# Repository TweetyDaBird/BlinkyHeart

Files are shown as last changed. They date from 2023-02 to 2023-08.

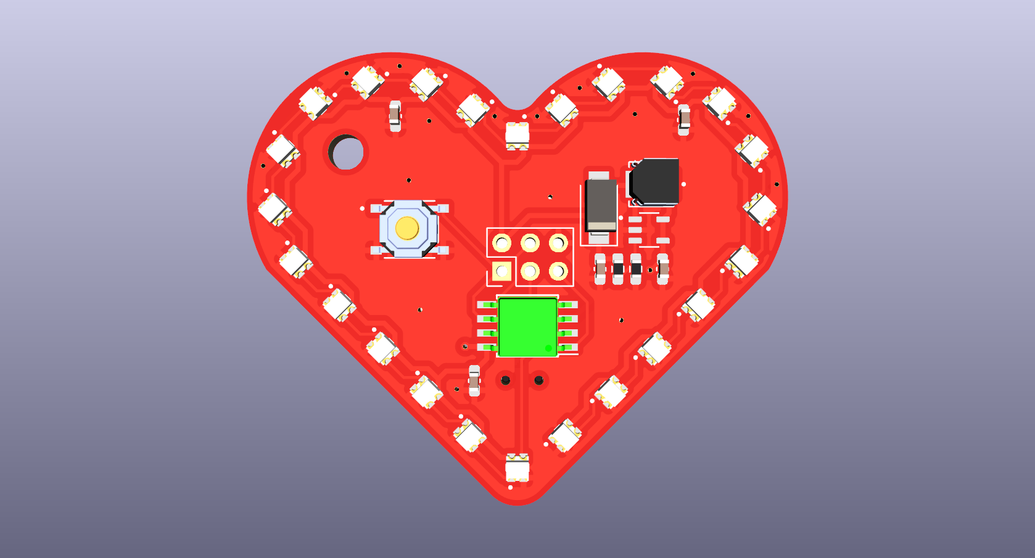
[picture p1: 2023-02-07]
BlinkyHeart/BlinkyHeart.png

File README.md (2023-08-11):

# BlinkyRGB
Blinky RGB Keychains in various shapes and sizes.

Uses an Microchip ATTINY85 MCU, and is powered by a CR2032 coin cell.

BlinkyHeart
BlinkyHeart_back
BlinkyStar
BlinkySmiley

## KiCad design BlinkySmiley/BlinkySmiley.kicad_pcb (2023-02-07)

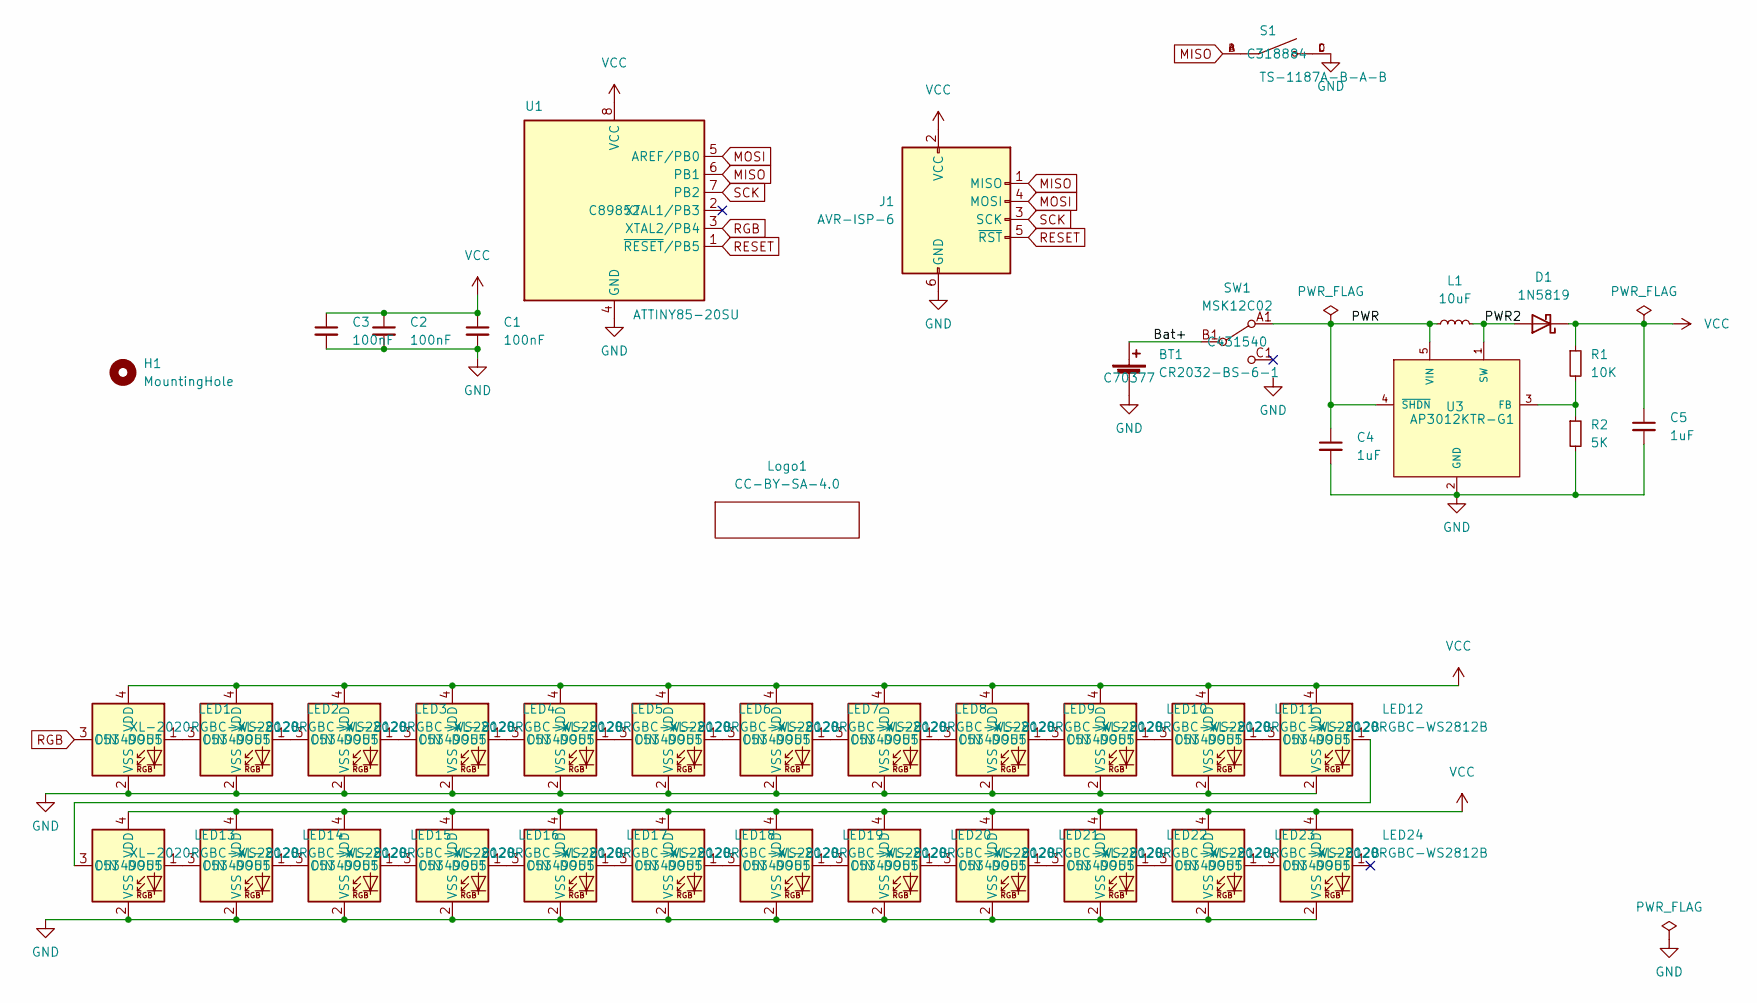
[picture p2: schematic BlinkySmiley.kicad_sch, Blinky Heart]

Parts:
BT1: CR2032-BS-6-1; BAT_CR2032-BS-6-1; LCSC C70377
C1, C2, C3: 100nF; C_0603_1608Metric_Pad1.08x0.95mm_HandSolder; LCSC C14663
C4, C5: 1uF; C_0603_1608Metric_Pad1.08x0.95mm_HandSolder; LCSC C15849
D1: 1N5819; D_SMA; LCSC C437199
H1: MountingHole; MountingHole_3.2mm_M3
J1: AVR-ISP-6; PinHeader_2x03_P2.54mm_Vertical
L1: 10uF; IND_FDSD0420-H-100M=P3; LCSC C1329533
LED1, LED2, LED3, LED4, LED5, LED6, LED7, LED8, LED9, LED10, LED11, LED12, LED13, LED14, LED15, LED16, LED17, LED18, LED19, LED20, LED21, LED22, LED23, LED24: XL-2020RGBC-WS2812B; LED_WS2812-2020; LCSC C5349955
Logo1: CC-BY-SA-4.0; CC_BY_SA_40
R1: 10K; R_0603_1608Metric_Pad0.98x0.95mm_HandSolder; LCSC C3017715
R2: 5K; R_0603_1608Metric_Pad0.98x0.95mm_HandSolder; LCSC C2828621
S1: TS-1187A-B-A-B; SW_TS-1187A-B-A-B; PARTREV A0; LCSC C318884
SW1: MSK12C02; LCSC C431540
U1: ATTINY85-20SU; SOIC-8W_5.3x5.3mm_P1.27mm; LCSC C89852
U3: AP3012KTR-G1; SOT95P280X145-5N; PARTREV 1.6; LCSC C102618

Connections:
/Bat+: BT1.1 (+), SW1.B1 (COM)
/PWR: C4.1, L1.1, SW1.A1 (A), U3.4 (~SHDN), U3.5 (VIN)
/PWR2: D1.2 (A), L1.2, U3.1 (SW)
GND: BT1.2 (-), C1.2, C2.2, C3.2, C4.2, C5.2, J1.6 (GND), LED1.2 (VSS), LED2.2 (VSS), LED3.2 (VSS), LED4.2 (VSS), LED5.2 (VSS), LED6.2 (VSS), LED7.2 (VSS), LED8.2 (VSS), LED9.2 (VSS), LED10.2 (VSS), LED11.2 (VSS), LED12.2 (VSS), LED13.2 (VSS), LED14.2 (VSS), LED15.2 (VSS), LED16.2 (VSS), LED17.2 (VSS), LED18.2 (VSS), LED19.2 (VSS), LED20.2 (VSS), LED21.2 (VSS), LED22.2 (VSS), LED23.2 (VSS), LED24.2 (VSS), R2.2, S1.C, S1.D, SW1.MP (GND), U1.4 (GND), U3.2 (GND)
MISO: J1.1 (MISO), S1.A, S1.B, U1.6 (PB1)
MOSI: J1.4 (MOSI), U1.5 (AREF/PB0)
unnamed: LED1.1 (DOUT), LED2.3 (DIN)
unnamed: LED2.1 (DOUT), LED3.3 (DIN)
unnamed: LED3.1 (DOUT), LED4.3 (DIN)
unnamed: LED4.1 (DOUT), LED5.3 (DIN)
unnamed: LED5.1 (DOUT), LED6.3 (DIN)
unnamed: LED6.1 (DOUT), LED7.3 (DIN)
unnamed: LED7.1 (DOUT), LED8.3 (DIN)
unnamed: LED8.1 (DOUT), LED9.3 (DIN)
unnamed: LED10.1 (DOUT), LED11.3 (DIN)
unnamed: LED9.1 (DOUT), LED10.3 (DIN)
unnamed: LED11.1 (DOUT), LED12.3 (DIN)
unnamed: LED12.1 (DOUT), LED13.3 (DIN)
unnamed: LED13.1 (DOUT), LED14.3 (DIN)
unnamed: LED14.1 (DOUT), LED15.3 (DIN)
unnamed: LED15.1 (DOUT), LED16.3 (DIN)
unnamed: LED16.1 (DOUT), LED17.3 (DIN)
unnamed: LED17.1 (DOUT), LED18.3 (DIN)
unnamed: LED18.1 (DOUT), LED19.3 (DIN)
unnamed: LED19.1 (DOUT), LED20.3 (DIN)
unnamed: LED20.1 (DOUT), LED21.3 (DIN)
unnamed: LED21.1 (DOUT), LED22.3 (DIN)
unnamed: LED22.1 (DOUT), LED23.3 (DIN)
unnamed: LED23.1 (DOUT), LED24.3 (DIN)
unnamed: R1.2, R2.1, U3.3 (FB)
RESET: J1.5 (~RST), U1.1 (~RESET/PB5)
RGB: LED1.3 (DIN), U1.3 (XTAL2/PB4)
SCK: J1.3 (SCK), U1.7 (PB2)
VCC: C1.1, C2.1, C3.1, C5.1, D1.1 (K), J1.2 (VCC), LED1.4 (VDD), LED2.4 (VDD), LED3.4 (VDD), LED4.4 (VDD), LED5.4 (VDD), LED6.4 (VDD), LED7.4 (VDD), LED8.4 (VDD), LED9.4 (VDD), LED10.4 (VDD), LED11.4 (VDD), LED12.4 (VDD), LED13.4 (VDD), LED14.4 (VDD), LED15.4 (VDD), LED16.4 (VDD), LED17.4 (VDD), LED18.4 (VDD), LED19.4 (VDD), LED20.4 (VDD), LED21.4 (VDD), LED22.4 (VDD), LED23.4 (VDD), LED24.4 (VDD), R1.1, U1.8 (VCC)

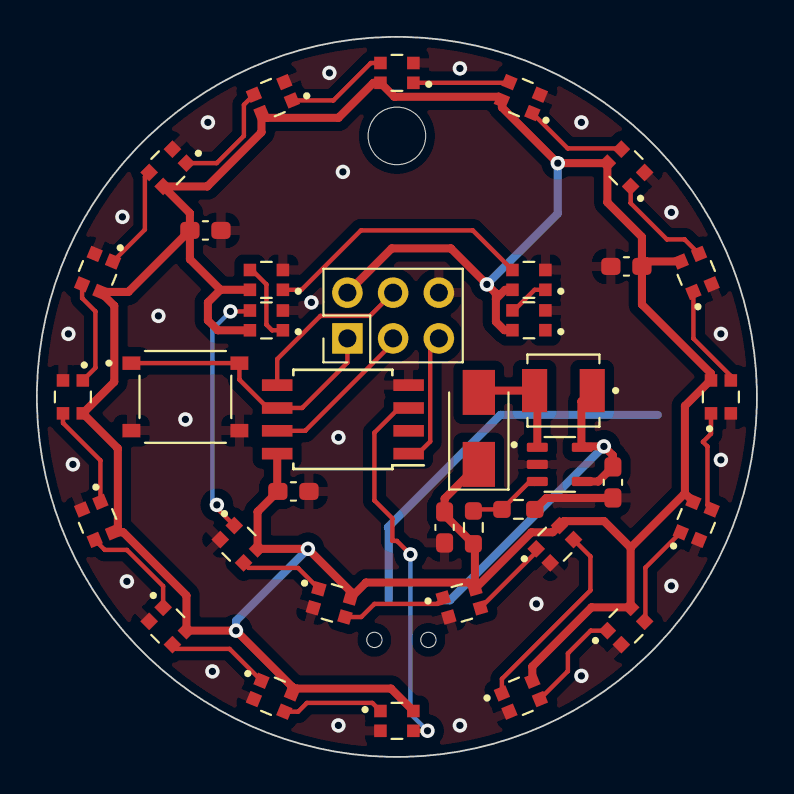
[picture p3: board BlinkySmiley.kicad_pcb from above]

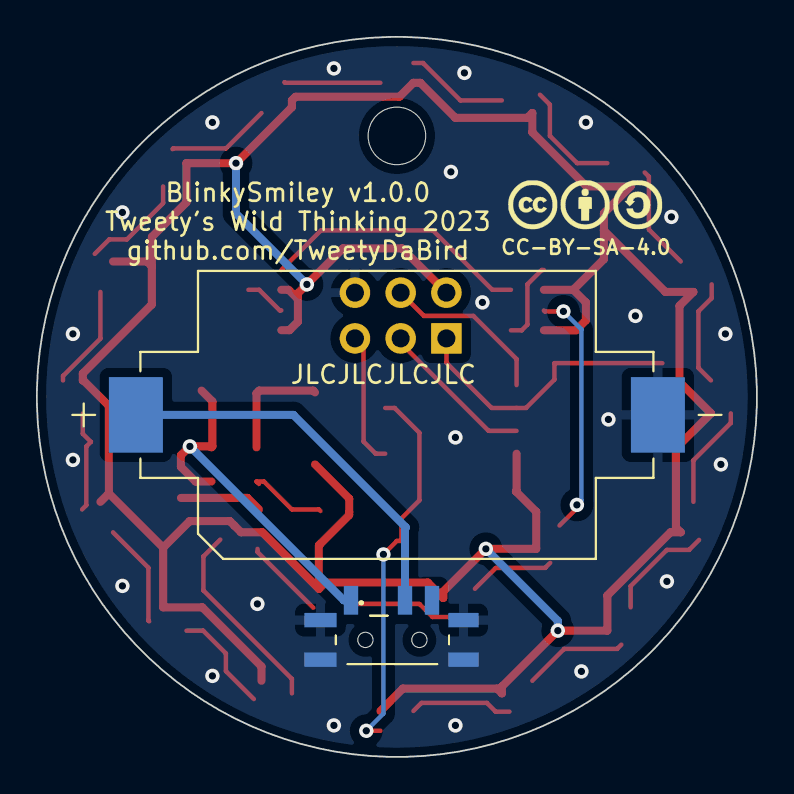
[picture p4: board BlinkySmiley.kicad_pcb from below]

Board: 2 copper layers, 40.0 x 40.0 mm, 41 parts (3 on the bottom side), 34 nets.

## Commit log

2023-02-06 silkscreen update
    [BlinkyHeart.kicad_pcb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]
2023-02-07 Added BlinkyStar
    [BlinkyHeart.kicad_pcb, BlinkyHeart.kicad_sch, BlinkyStar.kicad_pcb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]
2023-02-07 BlinkyStar BOM
2023-02-07 Added Blinky Smiley
    [BlinkySmiley.kicad_pcb, BlinkySmiley.kicad_sch, BlinkyStar.kicad_pcb]

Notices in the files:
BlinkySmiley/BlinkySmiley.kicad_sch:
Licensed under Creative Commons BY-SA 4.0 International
